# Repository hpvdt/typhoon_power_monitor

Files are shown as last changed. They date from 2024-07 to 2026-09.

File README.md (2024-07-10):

# Typhoon Power Monitor

General template repository for our hardware projects, especially one-off and self-contained projects like custom test equipment. This template assumes that the hardware is being designed in KiCad.

## Organization

Pretty self-explanitory, put hardware related files into the `hardware` folder, firmware in the `firmware` folder. Other folders can be added as needed: for example a `media` folder is handy for storing pictures related to a project which can be used in documentation.

## Conventions

Partly for consistency, partly for functionality; please follow the following conventions:

- Try to keep folder names to single words and all lowercase
- Use underscores to separate words in names (e.g. `board_rev1`). **DO NOT USE SPACES! ESPECIALLY FOR FOLDERS CONTAINING CODE!** Spaces in file paths may cause issues in compilers and such so best to avoid them entirely.

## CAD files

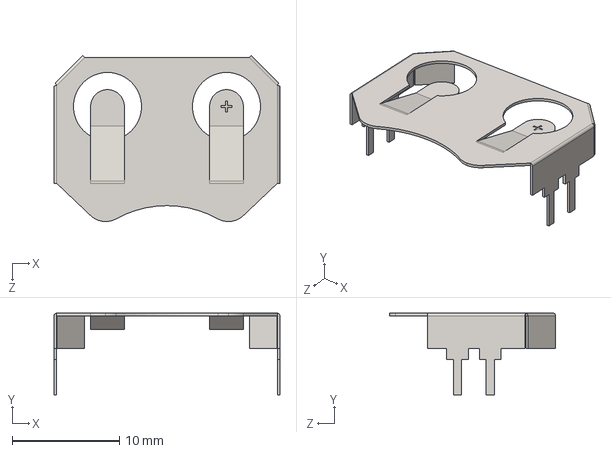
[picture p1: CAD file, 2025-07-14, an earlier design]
hardware/rev2/power_rev2/3dmodels/BAT-HLD-001-THM.stp
21.1 x 7.62 x 15.5 mm

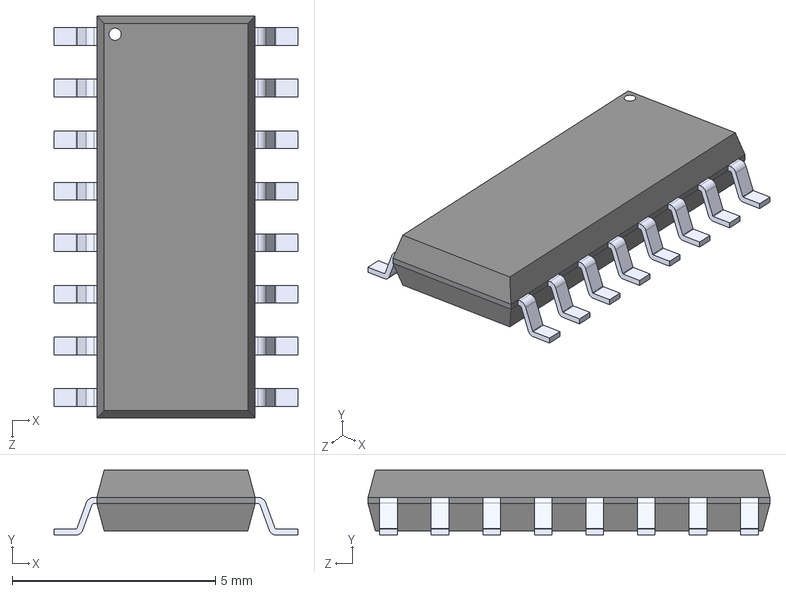
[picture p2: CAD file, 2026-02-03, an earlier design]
hardware/rev3/nexus_power_rev3/HX711/HX711.step
6.00 x 1.60 x 9.90 mm

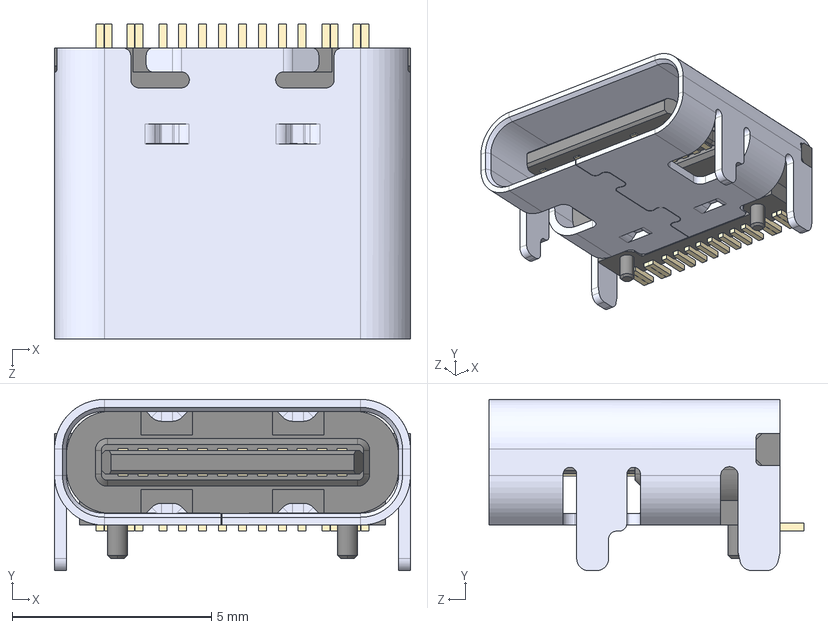
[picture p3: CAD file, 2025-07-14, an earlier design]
hardware/rev2/power_rev2/3dmodels/TYPE-C-31-M-12.step
8.94 x 4.30 x 7.90 mm

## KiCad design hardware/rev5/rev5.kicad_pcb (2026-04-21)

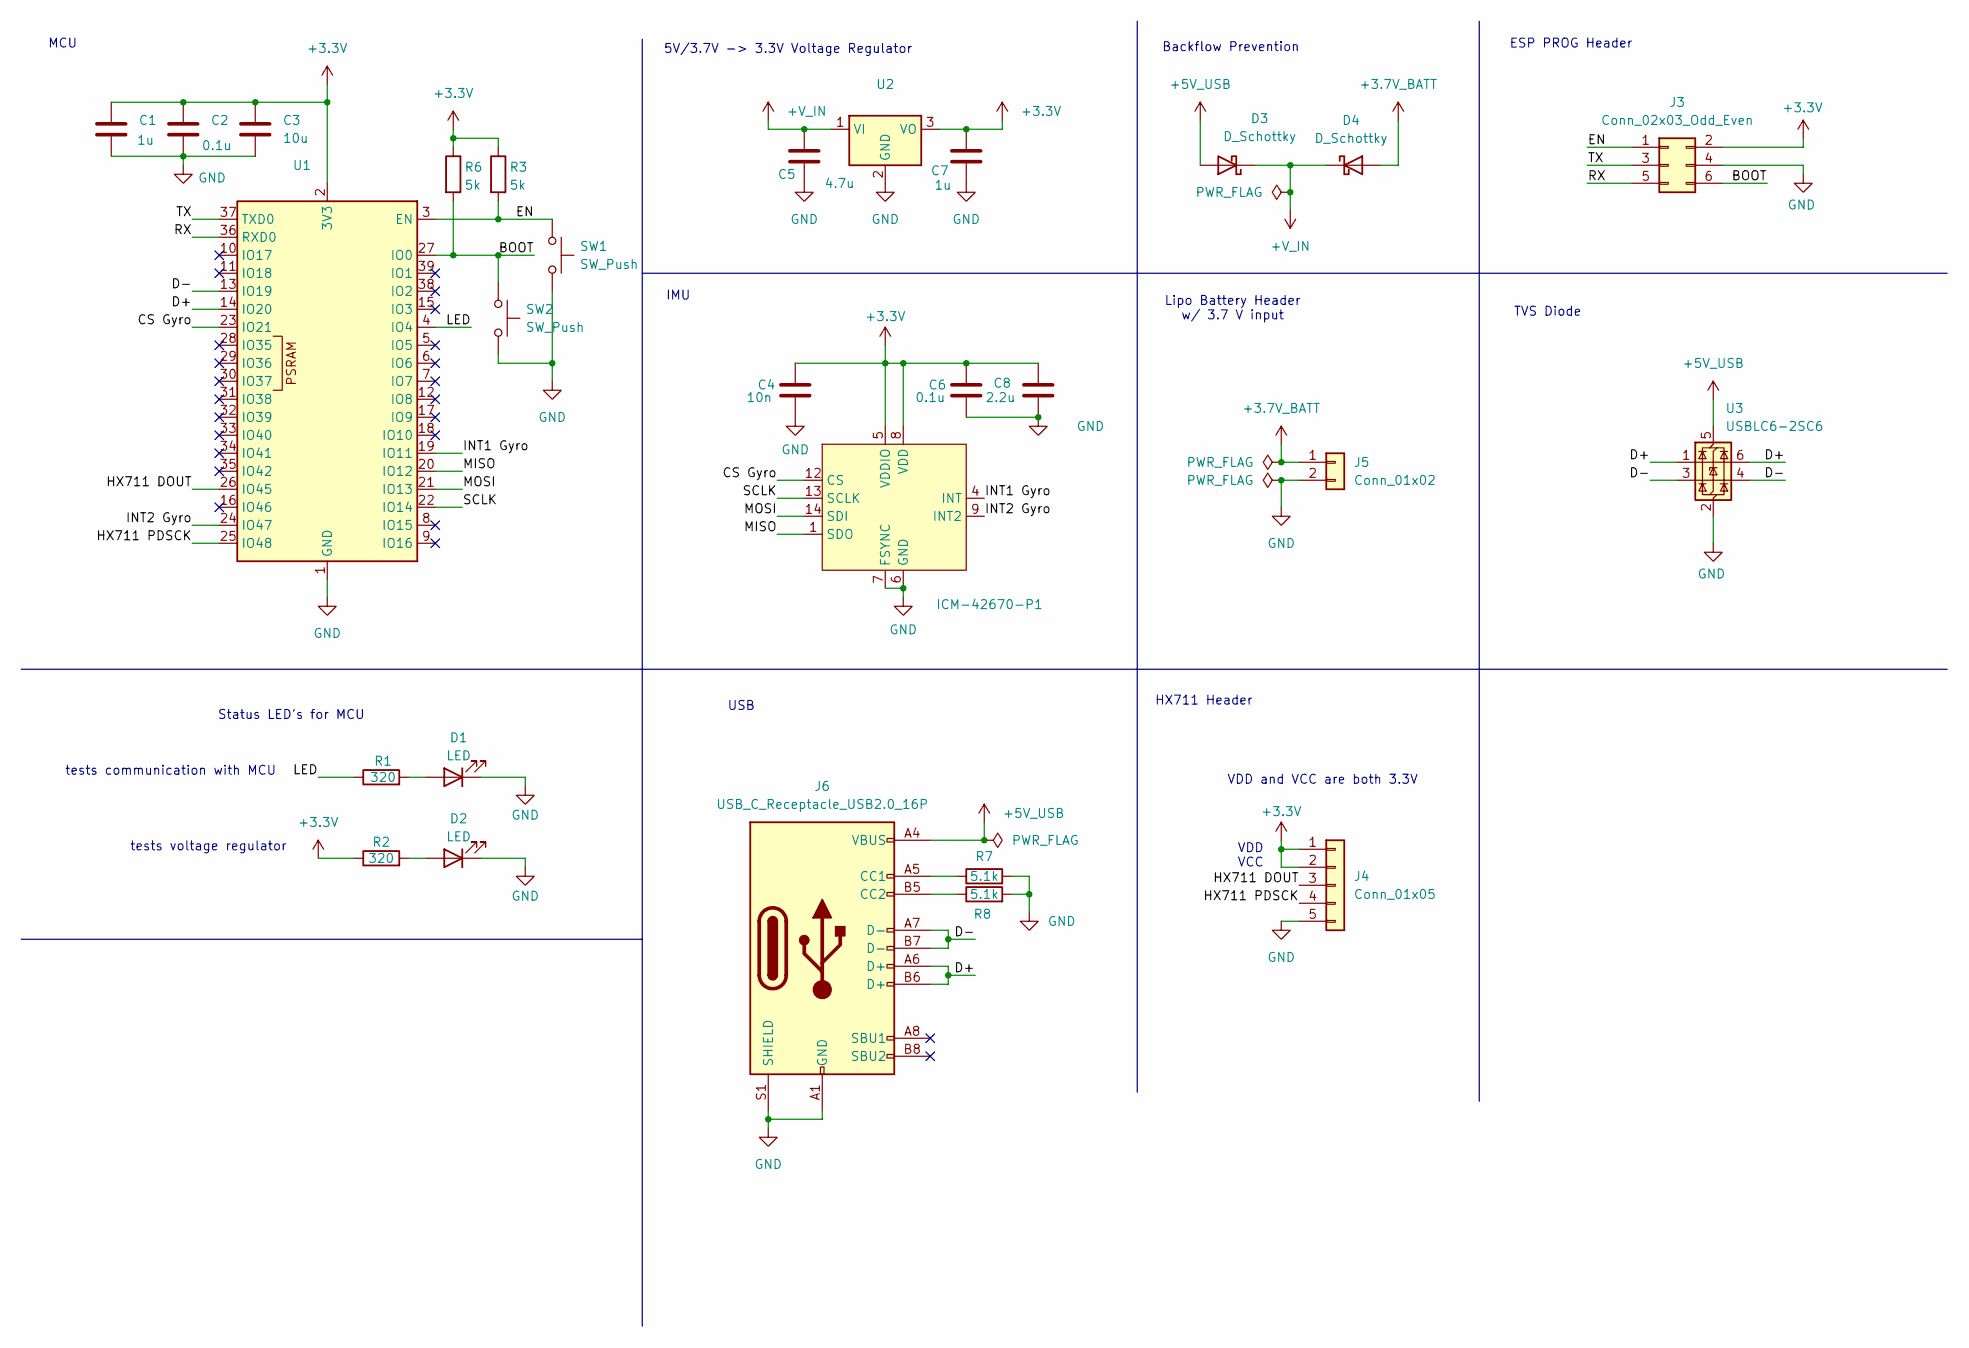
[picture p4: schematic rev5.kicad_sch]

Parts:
C1, C7: 1u; C_0805_2012Metric; Part number CL21B105KAFNNNE
C2, C6: 0.1u; C_0805_2012Metric; Part number C0805C104K5RACTU
C3: 10u; C_0805_2012Metric; Part number CL10A106KP8NNNC
C4: 10n; C_0805_2012Metric; Part number C0805C103K5RACTU
C5: 4.7u; C_0805_2012Metric; Part number CL21A475KAQNNNE
C8: 2.2u; C_0805_2012Metric; Part number CL21B225KAFNNNE
D1, D2: LED; LED_0805_2012Metric; Part number LTST-C170GKT
D3, D4: D_Schottky; D_SOD-123
ICM-42670-P1: LGA-14_3x2.5mm_P0.5mm_LayoutBorder3x4y; Part number ICM-42670-P
J3: Conn_02x03_Odd_Even; IDC-Header_2x03_P2.54mm_Vertical
J4: Conn_01x05; JST_XH_S5B-XH-A-1_1x05_P2.50mm_Horizontal
J5: Conn_01x02; JST_PH_S2B-PH-K_1x02_P2.00mm_Horizontal
J6: USB_C_Receptacle_USB2.0_16P; USB_C_Receptacle_JAE_DX07S016JA1R1500
R1, R2: 320; R_0805_2012Metric; Part number RT0805BRD07320RL
R3, R6: 5k; R_0805_2012Metric_Pad1.20x1.40mm_HandSolder
R7, R8: 5.1k; R_0805_2012Metric; Part number RMCF0805JT5K10
SW1, SW2: SW_Push; SW_SPST_SKQG_WithStem
U1: ESP32-S3-WROOM-1; Part number ESP32-S3-WROOM-1-N4R2
U2: SOT-223-3_TabPin2; Part number MCP1825ST-3302E/DB
U3: USBLC6-2SC6; SOT-23-6

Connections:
+3.3V: C1.1, C2.1, C3.1, C4.2, C6.2, C7.2, C8.2, ICM-42670-P1.5 (VDDIO), ICM-42670-P1.8 (VDD), J3.2, J4.1, J4.2, R2.1, R3.1, R6.1, U1.2 (3V3), U2.3 (VO); also elsewhere on the board
+3.7V_BATT: D4.2 (A), J5.1
+5V_USB: D3.2 (A), J6.A4 (VBUS), J6.A9 (VBUS), J6.B4 (VBUS), J6.B9 (VBUS), U3.5 (VBUS)
+V_IN: C5.2, D3.1 (K), D4.1 (K), U2.1 (VI)
/BOOT: J3.6, R6.2, SW2.1, U1.27 (IO0)
/CS Gyro: ICM-42670-P1.12 (CS), U1.23 (IO21); also elsewhere on the board
/D+: J6.A6 (D+), J6.B6 (D+), U1.14 (IO20), U3.1 (I/O1), U3.6 (I/O1)
/D-: J6.A7 (D-), J6.B7 (D-), U1.13 (IO19), U3.3 (I/O2), U3.4 (I/O2)
/EN: J3.1, R3.2, SW1.1, U1.3 (EN)
/HX711 DOUT: J4.3, U1.26 (IO45)
/HX711 PDSCK: J4.4, U1.25 (IO48)
/INT1 Gyro: ICM-42670-P1.4 (INT), U1.19 (IO11); also elsewhere on the board
/INT2 Gyro: ICM-42670-P1.9 (INT2), U1.24 (IO47); also elsewhere on the board
/LED: R1.1, U1.4 (IO4)
/MISO: ICM-42670-P1.1 (SDO), U1.20 (IO12); also elsewhere on the board
/MOSI: ICM-42670-P1.14 (SDI), U1.21 (IO13); also elsewhere on the board
/RX: J3.5, U1.36 (RXD0)
/SCLK: ICM-42670-P1.13 (SCLK), U1.22 (IO14); also elsewhere on the board
/TX: J3.3, U1.37 (TXD0)
GND: C1.2, C2.2, C3.2, C4.1, C5.1, C6.1, C7.1, C8.1, D1.1 (K), D2.1 (K), ICM-42670-P1.6 (GND), ICM-42670-P1.7 (FSYNC), J3.4, J4.5, J5.2, J6.A1 (GND), J6.A12 (GND), J6.B1 (GND), J6.B12 (GND), J6.S1 (SHIELD), R7.2, R8.2, SW1.2, SW2.2, U1.1 (GND), U1.40 (GND), U1.41 (GND), U2.2 (GND), U3.2 (GND); also elsewhere on the board
unnamed: D1.2 (A), R1.2
unnamed: D2.2 (A), R2.2
unnamed: J6.A5 (CC1), R7.1
unnamed: J6.B5 (CC2), R8.1

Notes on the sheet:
ESP PROG Header
Lipo Battery Header w/ 3.7 V input
Status LED's for MCU
MCU
TVS Diode
tests communication with MCU
IMU
VDD and VCC are both 3.3V
5V/3.7V -> 3.3V Voltage Regulator
tests voltage regulator
Backflow Prevention
HX711 Header
USB
VCC
VDD

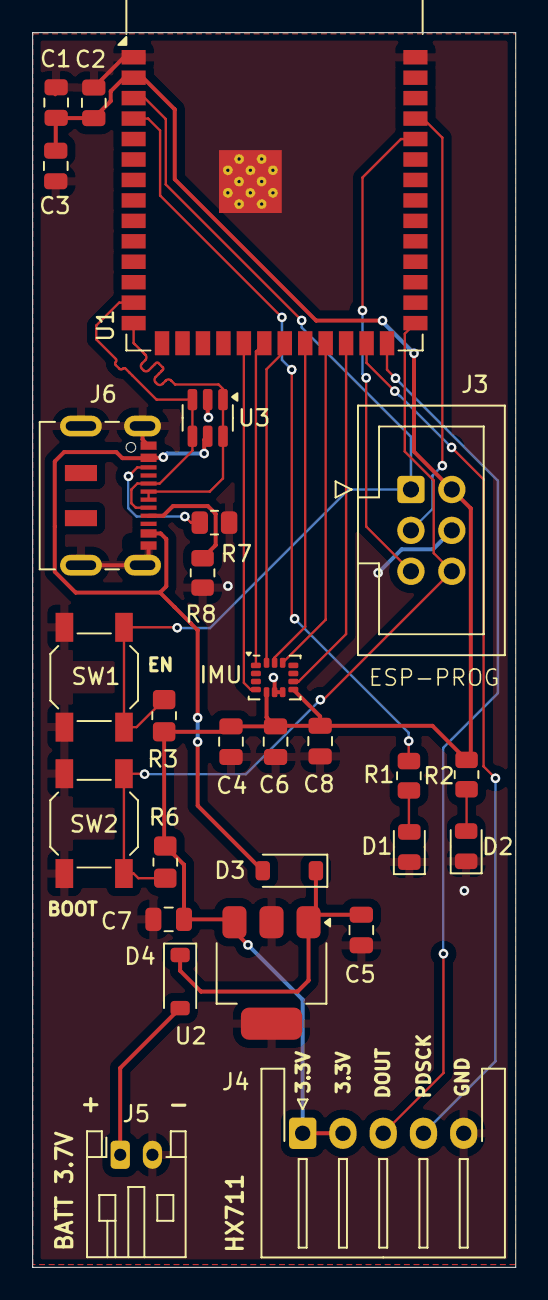
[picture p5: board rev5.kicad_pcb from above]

Board: 2 copper layers, 30.0 x 76.7 mm, 28 parts (0 on the bottom side), 24 nets.

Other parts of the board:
IMU: LGA-14_3x2.5mm_P0.5mm_LayoutBorder3x4y

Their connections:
+3.3V: IMU.5 (VDDIO), IMU.8 (VDD); also elsewhere on the board
/CS Gyro: IMU.12 (CS); also elsewhere on the board
/INT1 Gyro: IMU.4 (INT); also elsewhere on the board
/INT2 Gyro: IMU.9 (INT2); also elsewhere on the board
/MISO: IMU.1 (SDO); also elsewhere on the board
/MOSI: IMU.14 (SDI); also elsewhere on the board
/SCLK: IMU.13 (SCLK); also elsewhere on the board
GND: IMU.6 (GND), IMU.7 (FSYNC); also elsewhere on the board

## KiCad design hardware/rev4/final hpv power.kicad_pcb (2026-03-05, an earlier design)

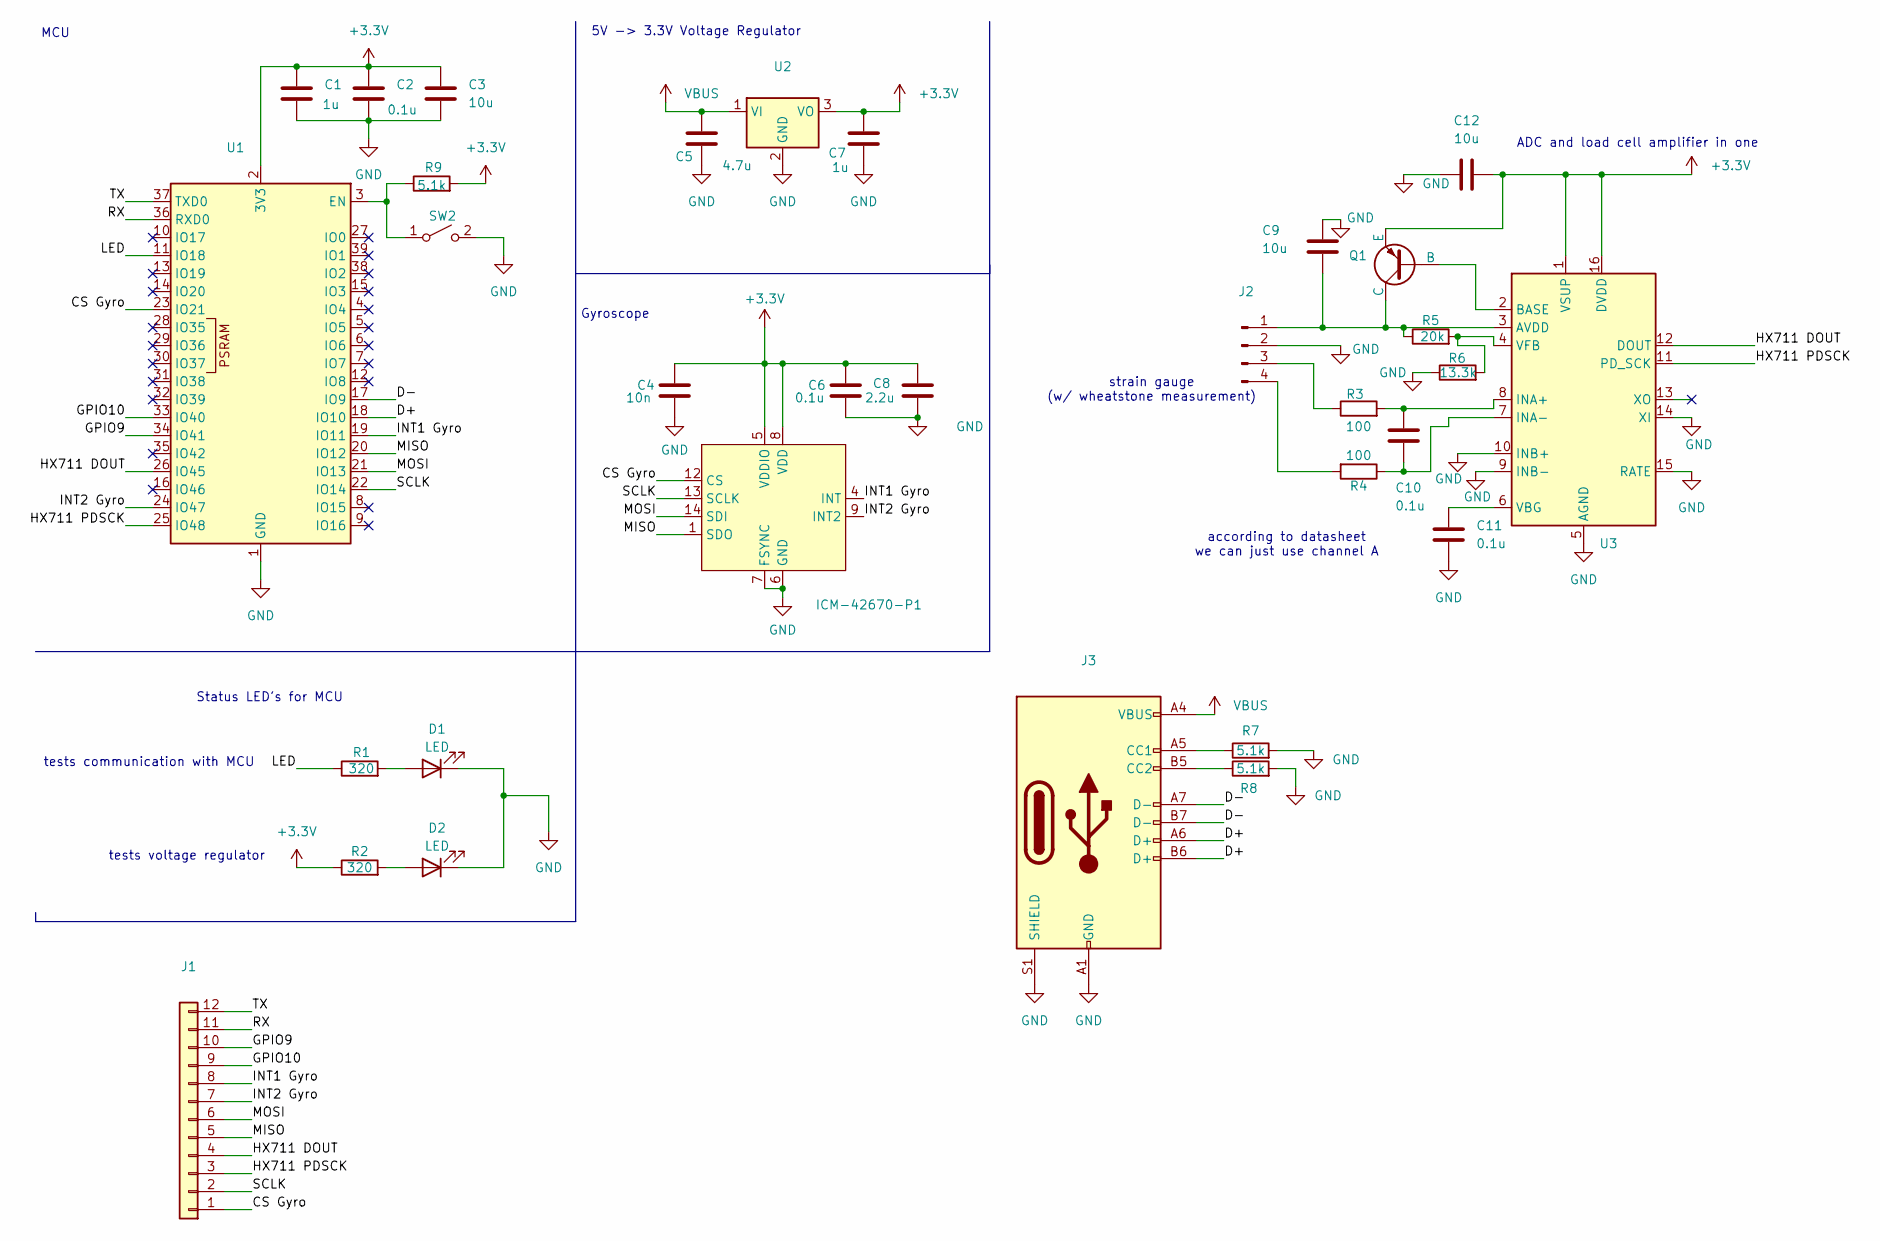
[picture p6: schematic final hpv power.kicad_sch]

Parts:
C1, C7: 1u; C_0805_2012Metric; Part number CL21B105KAFNNNE
C2, C6, C10, C11: 0.1u; C_0805_2012Metric; Part number C0805C104K5RACTU
C3, C9, C12: 10u; C_0805_2012Metric; Part number CL10A106KP8NNNC
C4: 10n; C_0805_2012Metric; Part number C0805C103K5RACTU
C5: 4.7u; C_0805_2012Metric; Part number CL21A475KAQNNNE
C8: 2.2u; C_0805_2012Metric; Part number CL21B225KAFNNNE
D1, D2: LED; LED_0805_2012Metric; Part number LTST-C170GKT
ICM-42670-P1: LGA-14_3x2.5mm_P0.5mm_LayoutBorder3x4y; Part number ICM-42670-P
J1: JST_EH_B12B-EH-A_1x12_P2.50mm_Vertical; Part number B12B-XH-A
J2: JST_EH_B4B-EH-A_1x04_P2.50mm_Vertical; Part number B4B-XH-A
J3: USB_C_Receptacle_GCT_USB4110; Part number USB4110-GF-A
Q1: SOT-23; Part number MMSS8550-L-TP
R1, R2: 320; R_0805_2012Metric; Part number RT0805BRD07320RL
R3, R4: 100; R_0805_2012Metric; Part number CRCW0805100RFKEA
R5: 20k; R_0805_2012Metric; Part number ERA-6AEB203V
R6: 13.3k; R_0805_2012Metric; Part number CRCW080513K3FKEA
R7, R8, R9: 5.1k; R_0805_2012Metric; Part number RMCF0805JT5K10
SW2: SW_PUSH_6mm_H4.3mm; Part number 1301.9314.24
U1: ESP32-S3-WROOM-1; Part number ESP32-S3-WROOM-1-N4R2
U2: SOT-223-3_TabPin2; Part number MCP1825ST-3302E/DB
U3: SOP127P600X180-16N; Part number 13879

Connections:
+3.3V: C1.1, C2.1, C3.1, C4.2, C6.2, C7.2, C8.2, C12.1, ICM-42670-P1.5 (VDDIO), ICM-42670-P1.8 (VDD), Q1.3 (E), R2.1, R9.2, U1.2 (3V3), U2.3 (VO), U3.1 (VSUP), U3.16 (DVDD)
/CS Gyro: ICM-42670-P1.12 (CS), J1.1, U1.23 (IO21)
/D+: J3.A6 (D+), J3.B6 (D+), U1.18 (IO10)
/D-: J3.A7 (D-), J3.B7 (D-), U1.17 (IO9)
/GPIO9: J1.10, U1.34 (IO41)
/GPIO10: J1.9, U1.33 (IO40)
/HX711 DOUT: J1.4, U1.26 (IO45), U3.12 (DOUT)
/HX711 PDSCK: J1.3, U1.25 (IO48), U3.11 (PD_SCK)
/INT1 Gyro: ICM-42670-P1.4 (INT), J1.8, U1.19 (IO11)
/INT2 Gyro: ICM-42670-P1.9 (INT2), J1.7, U1.24 (IO47)
/LED: R1.1, U1.11 (IO18)
/MISO: ICM-42670-P1.1 (SDO), J1.5, U1.20 (IO12)
/MOSI: ICM-42670-P1.14 (SDI), J1.6, U1.21 (IO13)
/RX: J1.11, U1.36 (RXD0)
/SCLK: ICM-42670-P1.13 (SCLK), J1.2, U1.22 (IO14)
/TX: J1.12, U1.37 (TXD0)
GND: C1.2, C2.2, C3.2, C4.1, C5.1, C6.1, C7.1, C8.1, C9.1, C11.2, C12.2, D1.1 (K), D2.1 (K), ICM-42670-P1.6 (GND), ICM-42670-P1.7 (FSYNC), J2.2, J3.A1 (GND), J3.A12 (GND), J3.B1 (GND), J3.B12 (GND), J3.S1 (SHIELD), R6.1, R7.2, R8.2, SW2.2 (B), U1.1 (GND), U1.40 (GND), U1.41 (GND), U2.2 (GND), U3.5 (AGND), U3.9 (INB-), U3.10 (INB+), U3.14 (XI), U3.15 (RATE)
unnamed: D1.2 (A), R1.2
unnamed: D2.2 (A), R2.2
unnamed: C9.2, J2.1, Q1.1 (C), R5.1, U3.3 (AVDD)
unnamed: J2.3, R3.1
unnamed: J2.4, R4.2
unnamed: J3.A5 (CC1), R7.1
unnamed: J3.B5 (CC2), R8.1
unnamed: Q1.2 (B), U3.2 (BASE)
unnamed: R9.1, SW2.1 (A), U1.3 (EN)
unnamed: C10.1, R3.2, U3.8 (INA+)
unnamed: C10.2, R4.1, U3.7 (INA-)
unnamed: C11.1, U3.6 (VBG)
unnamed: R5.2, R6.2, U3.4 (VFB)
VBUS: C5.2, J3.A4 (VBUS), J3.A9 (VBUS), J3.B4 (VBUS), J3.B9 (VBUS), U2.1 (VI)

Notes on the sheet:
strain gauge (w/ wheatstone measurement)
ADC and load cell amplifier in one
according to datasheet we can just use channel A
Status LED's for MCU
MCU
tests communication with MCU
Gyroscope
5V -> 3.3V Voltage Regulator
tests voltage regulator

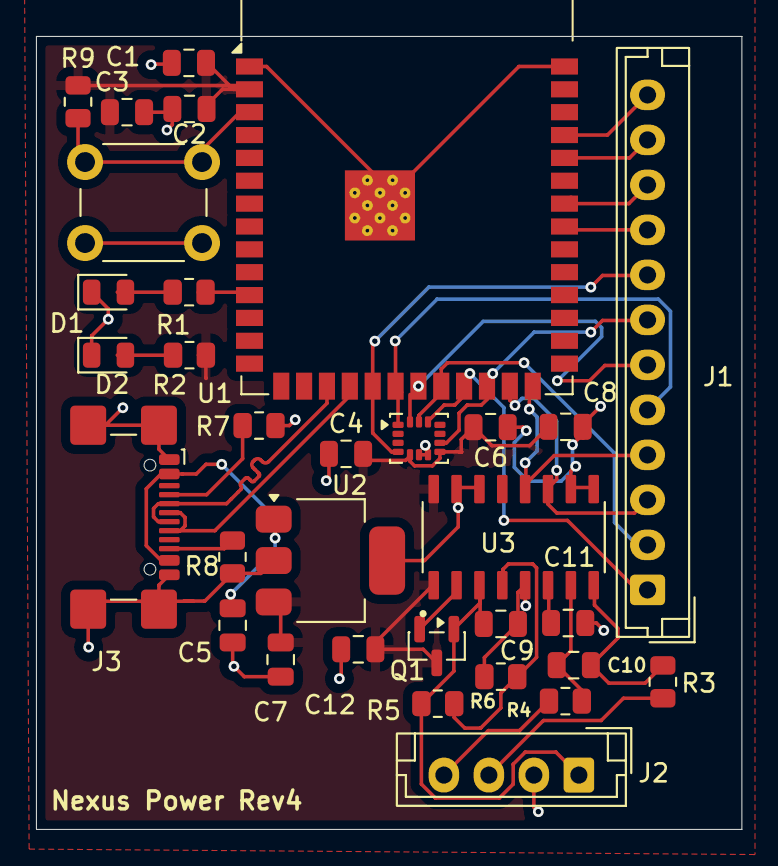
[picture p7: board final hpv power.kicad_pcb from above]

Board: 2 copper layers, 39.2 x 44.1 mm, 32 parts (0 on the bottom side), 31 nets.

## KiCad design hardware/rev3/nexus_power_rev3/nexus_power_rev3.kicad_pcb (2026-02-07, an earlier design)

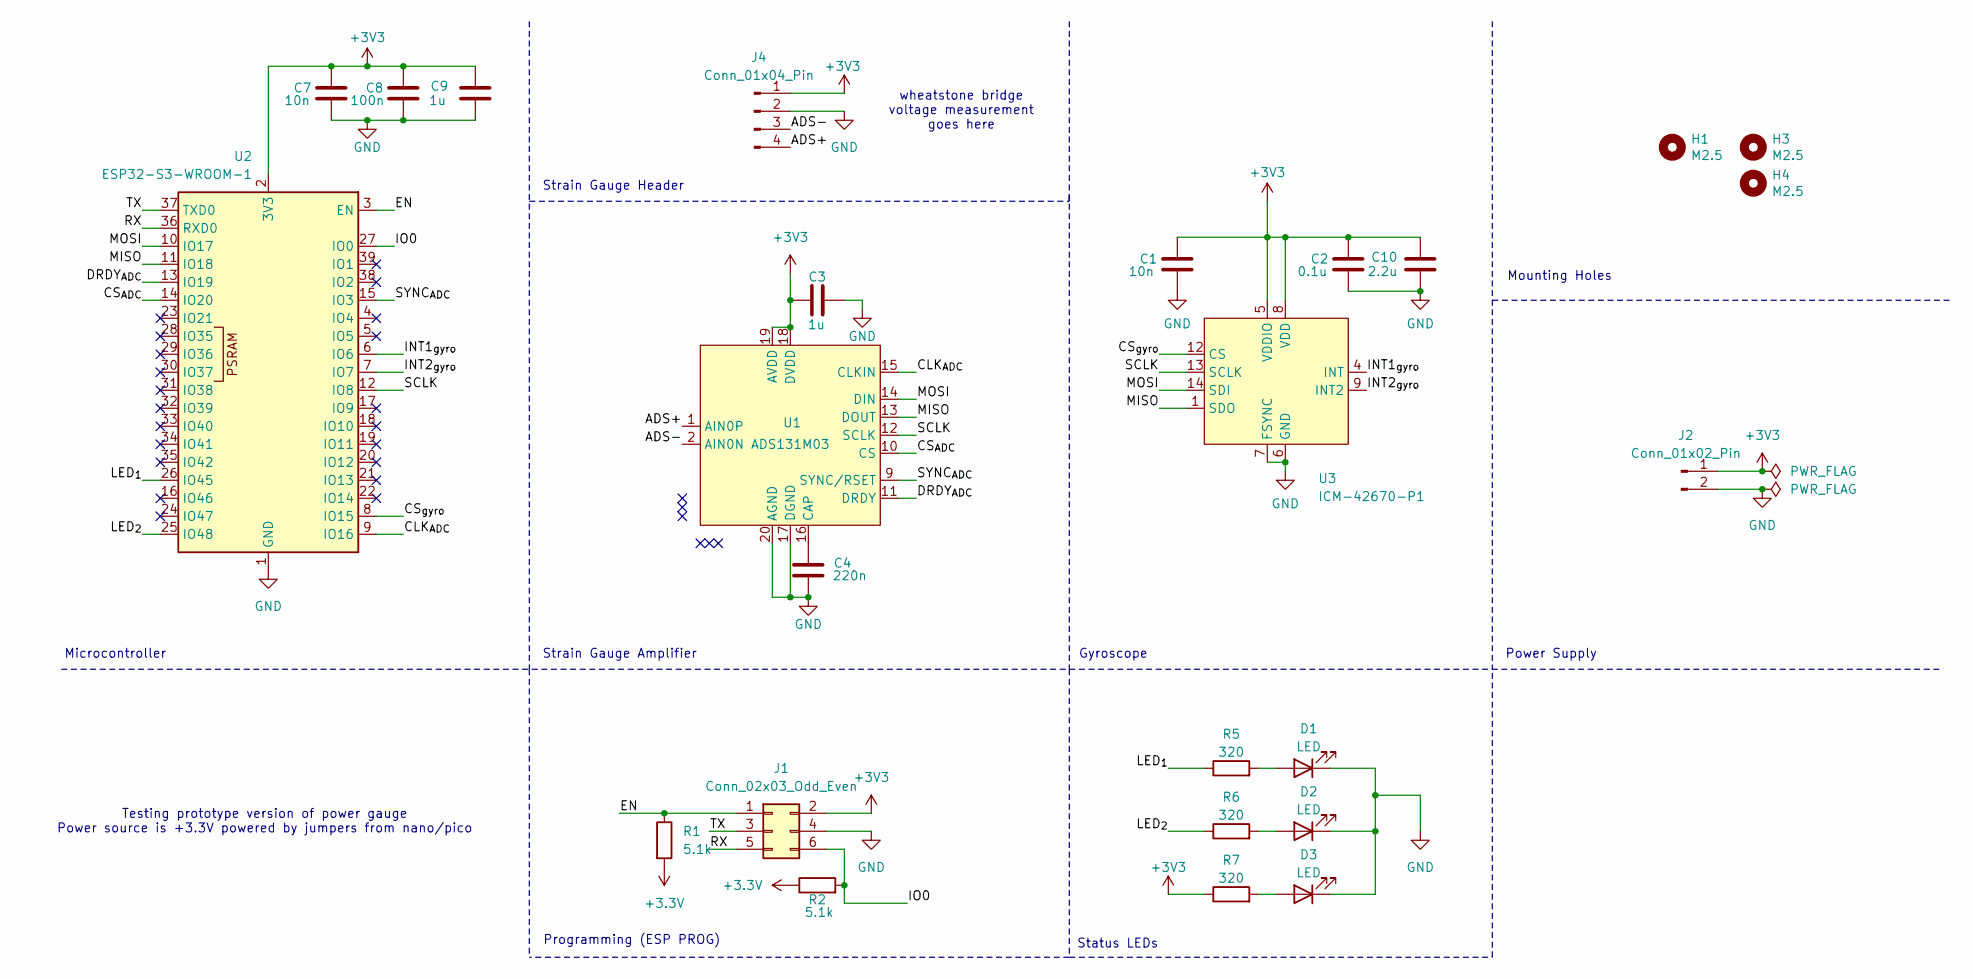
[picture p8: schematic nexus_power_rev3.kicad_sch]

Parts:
C1, C7: 10n; C_0603_1608Metric
C2: 0.1u; C_0603_1608Metric
C3, C9: 1u; C_0603_1608Metric
C4: 220n; C_0603_1608Metric
C8: 100n; C_0603_1608Metric
C10: 2.2u; C_0603_1608Metric
D1, D2, D3: LED; LED_0603_1608Metric
H1, H3, H4: M2.5; MountingHole_2.7mm_M2.5
J1: Conn_02x03_Odd_Even; IDC-Header_2x03_P2.54mm_Vertical
J2: Conn_01x02_Pin; PinHeader_1x02_P2.00mm_Vertical
J4: Conn_01x04_Pin; JST_XH_S4B-XH-A_1x04_P2.50mm_Horizontal
R1, R2: 5.1k; R_0603_1608Metric
R5, R6, R7: 320; R_0603_1608Metric
U1: ADS131M03; WQFN-20-1EP_3x3mm_P0.4mm_EP1.7x1.7mm
U2: ESP32-S3-WROOM-1
U3: ICM-42670-P1; LGA-14_3x2.5mm_P0.5mm_LayoutBorder3x4y

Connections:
+3.3V: R1.2, R2.1
+3V3: C1.2, C2.2, C3.2, C7.2, C8.2, C9.2, C10.2, J1.2, J2.1, J4.1, R7.1, U1.18 (DVDD), U1.19 (AVDD), U2.2 (3V3), U3.5 (VDDIO), U3.8 (VDD)
/ADS+: J4.4, U1.1 (AIN0P)
/ADS-: J4.3, U1.2 (AIN0N)
/CLK_{ADC}: U1.15 (CLKIN), U2.9 (IO16)
/CS_{ADC}: U1.10 (CS), U2.14 (IO20)
/CS_{gyro}: U2.8 (IO15), U3.12 (CS)
/DRDY_{ADC}: U1.11 (DRDY), U2.13 (IO19)
/EN: J1.1, R1.1, U2.3 (EN)
/INT1_{gyro}: U2.6 (IO6), U3.4 (INT)
/INT2_{gyro}: U2.7 (IO7), U3.9 (INT2)
/IO0: J1.6, R2.2, U2.27 (IO0)
/LED_{1}: R5.1, U2.26 (IO45)
/LED_{2}: R6.1, U2.25 (IO48)
/MISO: U1.13 (DOUT), U2.11 (IO18), U3.1 (SDO)
/MOSI: U1.14 (DIN), U2.10 (IO17), U3.14 (SDI)
/RX: J1.5, U2.36 (RXD0)
/SCLK: U1.12 (SCLK), U2.12 (IO8), U3.13 (SCLK)
/SYNC_{ADC}: U1.9 (SYNC/RSET), U2.15 (IO3)
/TX: J1.3, U2.37 (TXD0)
GND: C1.1, C2.1, C3.1, C4.1, C7.1, C8.1, C9.1, C10.1, D1.1 (K), D2.1 (K), D3.1 (K), J1.4, J2.2, J4.2, U1.17 (DGND), U1.20 (AGND), U2.1 (GND), U2.40 (GND), U2.41 (GND), U3.6 (GND), U3.7 (FSYNC)
unnamed: D1.2 (A), R5.2
unnamed: D2.2 (A), R6.2
unnamed: D3.2 (A), R7.2
unnamed: C4.2, U1.16 (CAP)

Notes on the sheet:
Programming (ESP PROG)
Strain Gauge Amplifier
Strain Gauge Header
Gyroscope
Microcontroller
Status LEDs
Testing prototype version of power gauge Power source is +3.3V powered by jumpers from nano/pico
wheatstone bridge voltage measurement goes here
Mounting Holes
Power Supply

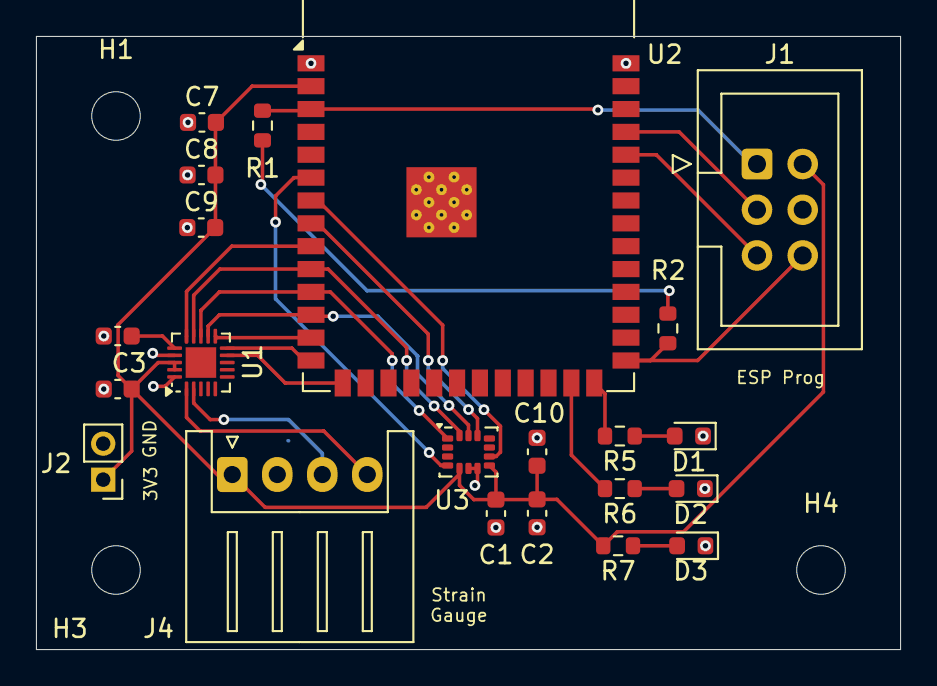
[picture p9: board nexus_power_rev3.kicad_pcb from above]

Board: 2 copper layers, 48.0 x 34.1 mm, 25 parts (0 on the bottom side), 25 nets.

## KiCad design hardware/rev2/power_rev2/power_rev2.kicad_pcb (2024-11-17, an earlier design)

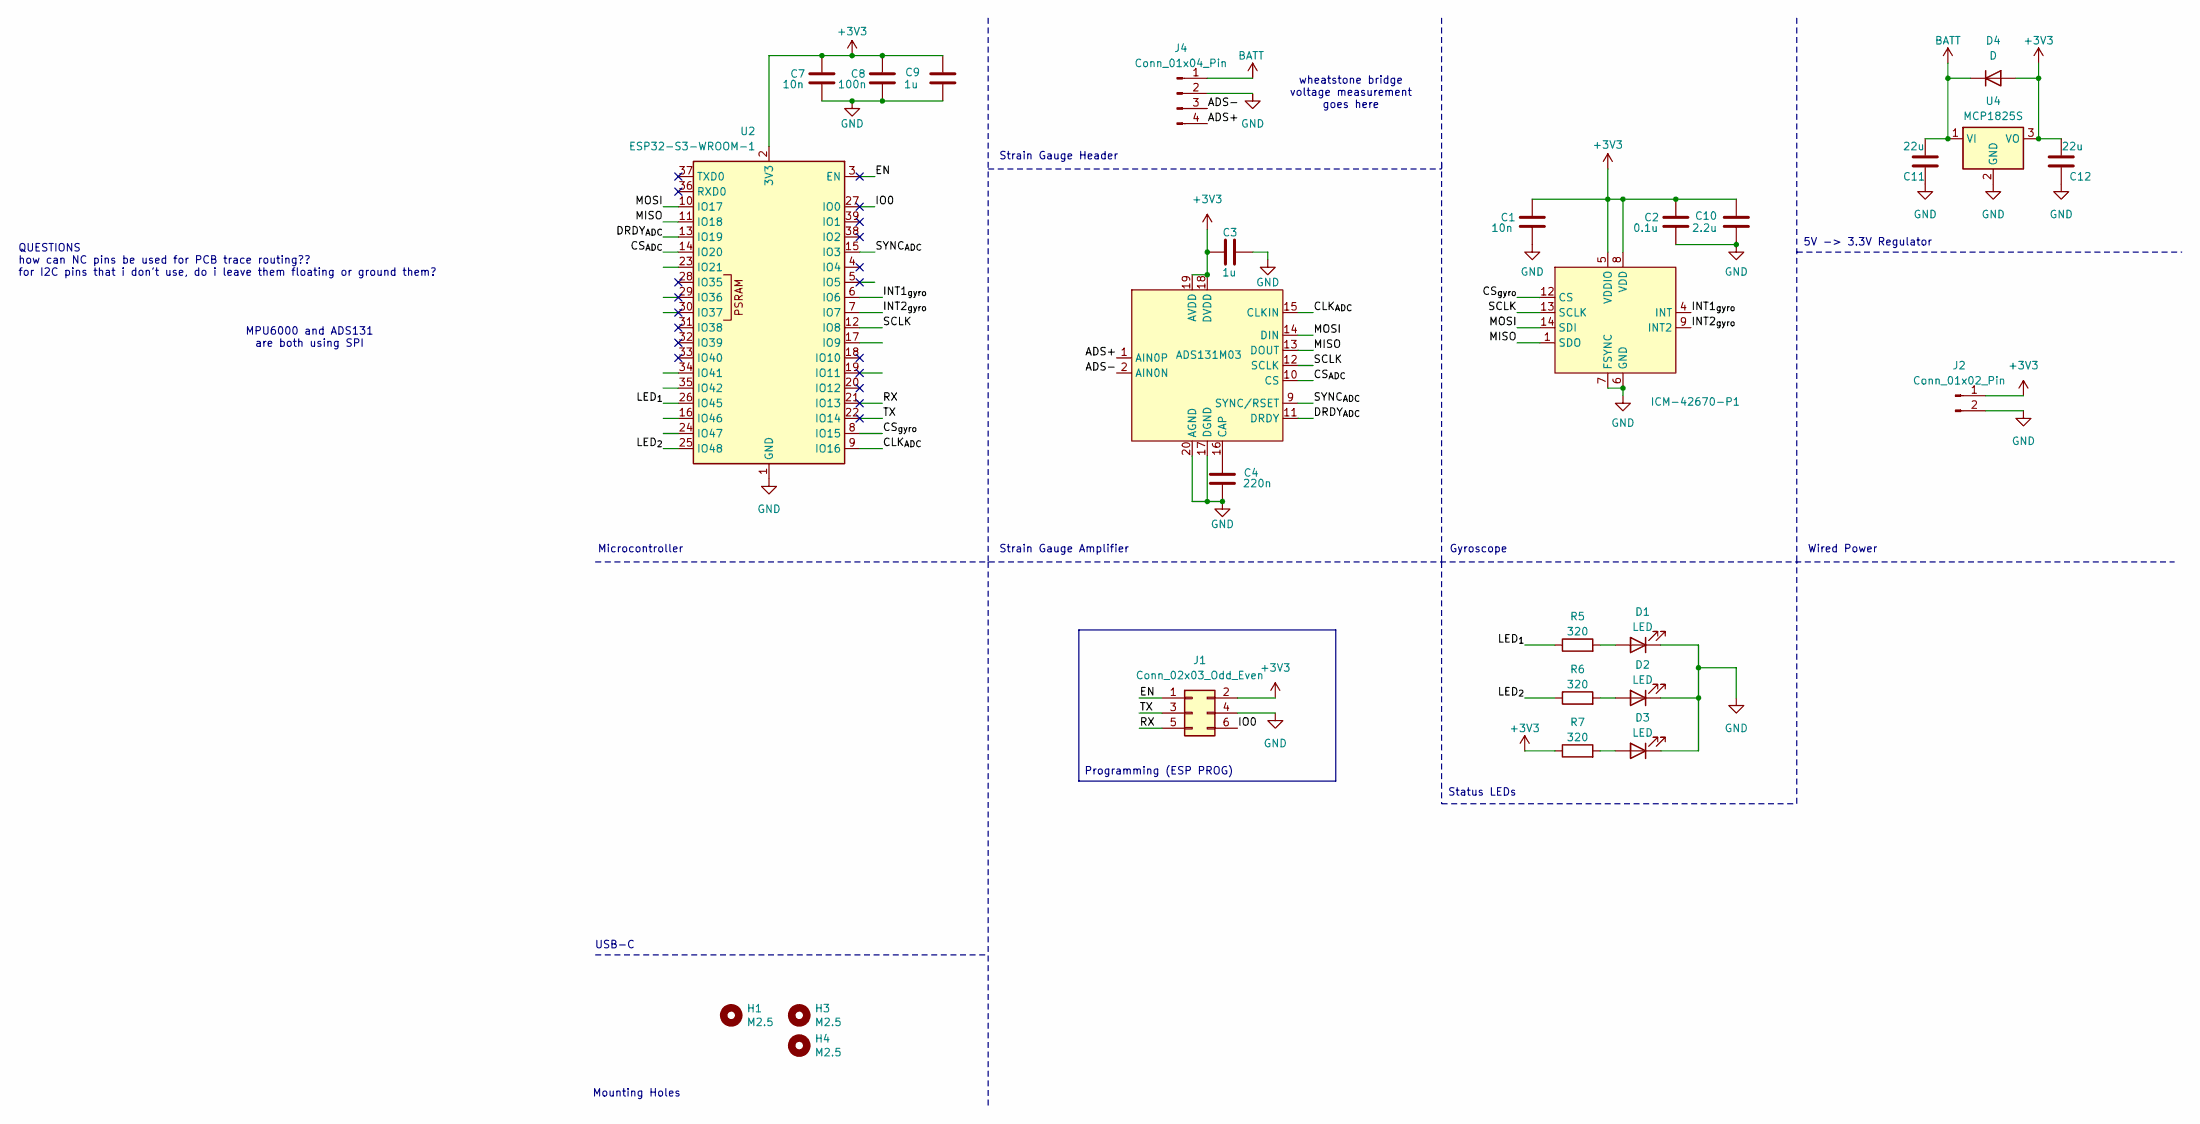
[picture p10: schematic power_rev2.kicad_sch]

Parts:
ADS131M03: ads
C1, C7: 10n; C_0402_1005Metric
C2: 0.1u; C_0402_1005Metric
C3, C9: 1u; C_0402_1005Metric
C4: 220n; C_0402_1005Metric
C8: 100n; C_0402_1005Metric
C10: 2.2u; C_0402_1005Metric
C11, C12: 22u; C_0402_1005Metric
D1, D2, D3: LED; LED_0402_1005Metric
D4: D; SD103CW
H1, H3, H4: M2.5; MountingHole_2.7mm_M2.5
ICM-42670-P1: LGA-14_3x2.5mm_P0.5mm_LayoutBorder3x4y
J1: Conn_02x03_Odd_Even; IDC-Header_2x03_P2.54mm_Vertical
J2: Conn_01x02_Pin; PinHeader_1x02_P1.27mm_Vertical
J4: Conn_01x04_Pin; JST_EH_S4B-EH_1x04_P2.50mm_Horizontal
R5, R6, R7: 320; R_0402_1005Metric
U2: ESP32-S3-WROOM-1
U4: MCP1825S; SOT-223-3_TabPin2

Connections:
+3V3: ADS131M03.18 (DVDD), ADS131M03.19 (AVDD), C1.2, C2.2, C3.2, C7.2, C8.2, C9.2, C10.2, C12.2, D4.2 (A), ICM-42670-P1.5 (VDDIO), ICM-42670-P1.8 (VDD), J1.2, J2.1, R7.1, U2.2 (3V3), U4.3 (VO)
/ADS+: ADS131M03.1 (AIN0P), J4.4
/ADS-: ADS131M03.2 (AIN0N), J4.3
/CLK_{ADC}: ADS131M03.15 (CLKIN), U2.9 (IO16)
/CS_{ADC}: ADS131M03.10 (CS), U2.14 (IO20)
/CS_{gyro}: ICM-42670-P1.12 (CS), U2.8 (IO15)
/DRDY_{ADC}: ADS131M03.11 (DRDY), U2.13 (IO19)
/EN: J1.1, U2.3 (EN)
/INT1_{gyro}: ICM-42670-P1.4 (INT), U2.6 (IO6)
/INT2_{gyro}: ICM-42670-P1.9 (INT2), U2.7 (IO7)
/IO0: J1.6, U2.27 (IO0)
/LED_{1}: R5.1, U2.26 (IO45)
/LED_{2}: R6.1, U2.25 (IO48)
/MISO: ADS131M03.13 (DOUT), ICM-42670-P1.1 (SDO), U2.11 (IO18)
/MOSI: ADS131M03.14 (DIN), ICM-42670-P1.14 (SDI), U2.10 (IO17)
/RX: J1.5, U2.21 (IO13)
/SCLK: ADS131M03.12 (SCLK), ICM-42670-P1.13 (SCLK), U2.12 (IO8)
/SYNC_{ADC}: ADS131M03.9 (SYNC/RSET), U2.15 (IO3)
/TX: J1.3, U2.22 (IO14)
BATT: C11.2, D4.1 (K), J4.1, U4.1 (VI)
GND: ADS131M03.17 (DGND), ADS131M03.20 (AGND), ADS131M03.21, C1.1, C2.1, C3.1, C4.1, C7.1, C8.1, C9.1, C10.1, C11.1, C12.1, D1.1 (K), D2.1 (K), D3.1 (K), ICM-42670-P1.6 (GND), ICM-42670-P1.7 (FSYNC), J1.4, J2.2, J4.2, U2.1 (GND), U2.40 (GND), U2.41 (GND), U4.2 (GND)
unnamed: ADS131M03.16 (CAP), C4.2
unnamed: D1.2 (A), R5.2
unnamed: D2.2 (A), R6.2
unnamed: D3.2 (A), R7.2

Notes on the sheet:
Strain Gauge Header
Strain Gauge Amplifier
wheatstone bridge voltage measurement goes here
Status LEDs
Mounting Holes
Programming (ESP PROG)
Microcontroller
5V -> 3.3V Regulator
MPU6000 and ADS131 are both using SPI
Wired Power
QUESTIONS how can NC pins be used for PCB trace routing?? for I2C pins that i don't use, do i leave them floating or ground them?
Gyroscope
USB-C

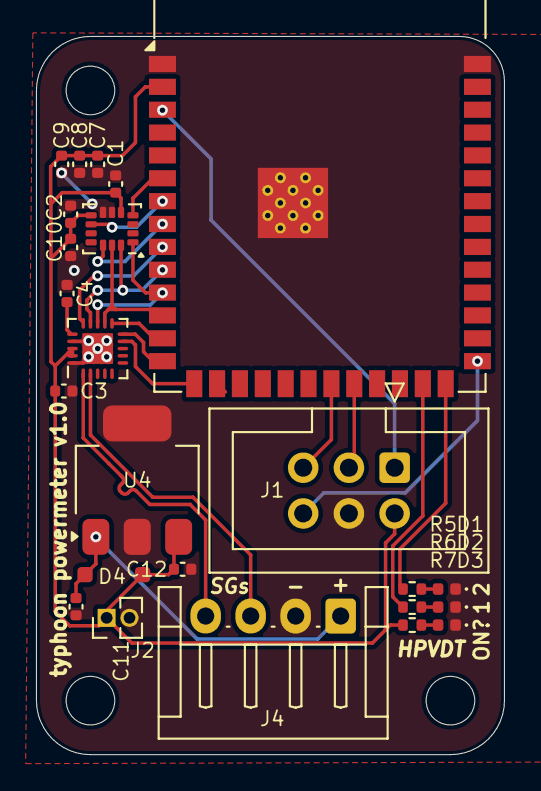
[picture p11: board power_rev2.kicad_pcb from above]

Board: 2 copper layers, 26.0 x 39.9 mm, 27 parts (0 on the bottom side), 25 nets.

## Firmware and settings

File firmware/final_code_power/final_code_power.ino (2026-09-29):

#include "ICM42670P.h"
#include <SPI.h>
#include <WiFi.h>
#include <WebServer.h>

// ======================================================
//                    WIFI SETTINGS
// ======================================================

const char* ssid = "ESP32-Data-Server";
const char* password = "12345678";

WebServer server(80);

// ======================================================
//                    BIKE CONSTANTS
// ======================================================

// in meters
const float crankLength = 0.06;
const float e = 2.7182818;

// ======================================================
//                    IMU PINS
// ======================================================

#define CS_pin 21
#define CLK_pin 14
#define MISO_pin 12
#define MOSI_pin 13

SPIClass* fspi = NULL;
ICM42670* IMU = NULL;

// ======================================================
//                    HX711 PINS
// ======================================================

const int hxClockPin = 48;
const int hxDataPin = 45;

// ======================================================
//                    GLOBAL VALUES
// ======================================================

float latestGyroX = 0;
float latestGyroY = 0;
float latestGyroZ = 0;

float latestAngularVelocity = 0;

float latestRawForce = 0;
float latestSlidingRaw = 0;    // 3-second sliding average raw force
float latestSlidingPower = 0;  // 3-second sliding average power

// Number of HX711 samples used for initial calibration
const int samples = 50;

float slope = 0;
float intercept = 0;

int initialForce = 0;

// ======================================================
//                3 SECOND TIMERS & WINDOWS
// ======================================================

const unsigned long measurementInterval = 1000;

// Time when the current measurement started
unsigned long measurementStartTime = 0;

// Sum of all HX711 readings during the period
long double hx711Sum = 0;

// Number of HX711 readings collected
unsigned long hx711Count = 0;

// IMU accumulation variables for 1-second averaging
float gyroSumX = 0;
float gyroSumY = 0;
float gyroSumZ = 0;
float angVelSum = 0;
unsigned long imuSampleCount = 0;

// 3-Second Sliding Window Buffers
const int windowSize = 3;
float powerWindow[windowSize] = { 0, 0, 0 };
int windowIndex = 0;

float rawWindow[windowSize] = { 0, 0, 0 };
int rawWindowIndex = 0;

// ======================================================
//                    HX711 FUNCTION
// ======================================================

long readHX711() {

  long count = 0;

  // Wait until HX711 is ready
  while (digitalRead(hxDataPin) == HIGH)
    ;

  // Read 24 bits
  for (int i = 0; i < 24; i++) {

    digitalWrite(hxClockPin, HIGH);

    count = count << 1;

    if (digitalRead(hxDataPin)) {
      count++;
    }

    digitalWrite(hxClockPin, LOW);
  }

  // 25th pulse → gain = 128
  digitalWrite(hxClockPin, HIGH);
  digitalWrite(hxClockPin, LOW);

  // Convert 24-bit signed value
  if (count & 0x800000) {
    count |= ~0xFFFFFF;
  }

  return count;
}

// ======================================================
//                    WEBSITE
// ======================================================

void handleRoot() {

  String html = R"rawliteral(
    <!DOCTYPE html>
    <html>

    <head>
      <title>ESP32 Power Meter</title>

      <style>

        body {
          font-family: Arial;
          text-align: center;
          margin-top: 40px;
        }

        .box {
          font-size: 28px;
          margin: 15px;
        }

      </style>

      <script>

        function updateData() {

          fetch('/data')
            .then(response => response.json())
            .then(data => {

              document.getElementById('gyroX').textContent = data.gyroX;
              document.getElementById('gyroY').textContent = data.gyroY;
              document.getElementById('gyroZ').textContent = data.gyroZ;
              document.getElementById('angularVelocity').textContent = data.angularVelocity;
              document.getElementById('rawValue').textContent = data.raw;
              document.getElementById('slidingRaw').textContent = data.slidingRaw;
              document.getElementById('slidingPower').textContent = data.slidingPower;

            });

        }

        setInterval(updateData, 1000);

        // Get the first reading immediately
        updateData();

      </script>

    </head>

    <body>

      <h1>ESP32 Cycling Power Meter</h1>

      <div class="box">
        <b>Gyro X:</b>
        <span id="gyroX">0</span> rad/s
      </div>

      <div class="box">
        <b>Gyro Y:</b>
        <span id="gyroY">0</span> rad/s
      </div>

      <div class="box">
        <b>Gyro Z:</b>
        <span id="gyroZ">0</span> rad/s
      </div>

      <div class="box">
        <b>Angular Velocity:</b>
        <span id="angularVelocity">0</span> rad/s
      </div>

      <div class="box">
        <b>Average Raw HX711:</b>
        <span id="rawValue">0</span>
      </div>

      <div class="box">
        <b>3-Sec Sliding Raw HX711:</b>
        <span id="slidingRaw">0</span>
      </div>

      <div class="box">
        <b>3-Sec Average Power:</b> 
        <span id="slidingPower">0</span> W
      </div>

    </body>
    </html>
  )rawliteral";

  server.send(200, "text/html", html);
}

// ======================================================
//      SEND ALL LIVE DATA TO THE WEBSITE
// ======================================================

void handleData() {

  String json = "{";

  json += "\"gyroX\":" + String(latestGyroX, 3) + ",";
  json += "\"gyroY\":" + String(latestGyroY, 3) + ",";
  json += "\"gyroZ\":" + String(latestGyroZ, 3) + ",";
  json += "\"angularVelocity\":" + String(latestAngularVelocity, 3) + ",";
  json += "\"raw\":" + String(latestRawForce, 0) + ",";
  json += "\"slidingRaw\":" + String(latestSlidingRaw, 0) + ",";
  json += "\"slidingPower\":" + String(latestSlidingPower, 2);

  json += "}";

  server.send(200, "application/json", json);
}

// ======================================================
//                        SETUP
// ======================================================

void setup() {

  int ret;

  Serial.begin(115200);

  // ---------- IMU setup ----------

  fspi = new SPIClass(FSPI);

  fspi->begin(CLK_pin, MISO_pin, MOSI_pin, CS_pin);

  pinMode(CS_pin, OUTPUT);

  digitalWrite(CS_pin, HIGH);

  IMU = new ICM42670(*fspi, CS_pin);

  // Manual WHO_AM_I check
  digitalWrite(CS_pin, LOW);

  fspi->transfer(0x75 | 0x80);

  uint8_t who_am_i = fspi->transfer(0x00);

  digitalWrite(CS_pin, HIGH);

  Serial.print("Manual WHO_AM_I check: 0x");
  Serial.println(who_am_i, HEX);

  if (who_am_i != 0x67) {

    Serial.println("WARNING: Chip ID mismatch!");

  } else {

    Serial.println("IMU detected correctly.");
  }

  ret = IMU->begin();

  Serial.print("IMU begin returned: ");
  Serial.println(ret);

  if (ret != 0) {

    Serial.println("IMU initialization failed");

    while (1)
      ;
  }

  IMU->startAccel(100, 16);
  IMU->startGyro(100, 2000);

  // ---------- HX711 setup ----------

  pinMode(hxClockPin, OUTPUT);
  pinMode(hxDataPin, INPUT);

  delay(100);

  // ======================================================
  //                    INITIAL CALIBRATION
  // ======================================================


  for (int i = 0; i < samples; i++) {

    initialForce += readHX711();
  }

  initialForce /= samples;

  // ======================================================
  //                    WIFI SETUP
  // ======================================================

  WiFi.softAP(ssid, password);

  Serial.println("Access Point Started");

  IPAddress IP = WiFi.softAPIP();

  Serial.print("ESP32 IP Address: ");
  Serial.println(IP);

  // ======================================================
  //                    WEBSITE ENDPOINTS
  // ======================================================

  server.on("/", handleRoot);

  server.on("/data", handleData);

  server.begin();

  Serial.println("Web server started");

  // Start the first measurement period
  measurementStartTime = millis();

  Serial.print("Initial HX711 average: ");
  Serial.println(initialForce);
}

// ======================================================
//                        LOOP
// ======================================================

void loop() {

  // ======================================================
  //                    READ IMU
  // ======================================================

  inv_imu_sensor_event_t imu_event;

  IMU->getDataFromRegisters(imu_event);

  float gyroX = imu_event.gyro[0] / 16.4 * 0.0174533;
  float gyroY = imu_event.gyro[1] / 16.4 * 0.0174533;
  float gyroZ = imu_event.gyro[2] / 16.4 * 0.0174533;

  float angularVelocity = sqrt(gyroX * gyroX + gyroY * gyroY + gyroZ * gyroZ);

  gyroSumX += gyroX;
  gyroSumY += gyroY;
  gyroSumZ += gyroZ;
  angVelSum += angularVelocity;
  imuSampleCount++;

  // ======================================================
  //                    READ HX711
  // ======================================================

  long measuredForce = readHX711();

  hx711Sum += abs(measuredForce - initialForce);
  hx711Count++;

  // Update every second
  if (millis() - measurementStartTime >= measurementInterval) {

    // 1. Calculate 1-second averages
    float avgGyroX = gyroSumX / imuSampleCount;
    float avgGyroY = gyroSumY / imuSampleCount;
    float avgGyroZ = gyroSumZ / imuSampleCount;
    float avgAngularVelocity = angVelSum / imuSampleCount;
    float averageHX711 = hx711Sum / hx711Count;

    // 2. Update 3-Second Sliding Window for Raw Force
    rawWindow[rawWindowIndex] = averageHX711;
    rawWindowIndex = (rawWindowIndex + 1) % windowSize;

    float rawSlidingSum = 0;
    for (int i = 0; i < windowSize; i++) {
      rawSlidingSum += rawWindow[i];
    }
    float slidingRaw = rawSlidingSum / windowSize;
    float torque = 0.000108 * slidingRaw - 0.744;

    // 3. Calculate 1-Second Power & Update 3-Second Sliding Power Window
    float oneSecondPower = torque * avgAngularVelocity;

    powerWindow[windowIndex] = oneSecondPower;
    windowIndex = (windowIndex + 1) % windowSize;

    float powerSlidingSum = 0;
    for (int i = 0; i < windowSize; i++) {
      powerSlidingSum += powerWindow[i];
    }
    float slidingPower = powerSlidingSum / windowSize;
    slidingPower -= 40;

    // 5. Save globals
    latestGyroX = avgGyroX;
    latestGyroY = avgGyroY;
    latestGyroZ = avgGyroZ;
    latestAngularVelocity = avgAngularVelocity;
    latestRawForce = averageHX711;
    latestSlidingRaw = slidingRaw;
    latestSlidingPower = slidingPower;

    Serial.print("lastestSlidingPower");
    Serial.println(latestSlidingPower);

    // 6. Reset ALL accumulators
    hx711Sum = 0;
    hx711Count = 0;
    gyroSumX = 0;
    gyroSumY = 0;
    gyroSumZ = 0;
    angVelSum = 0;
    imuSampleCount = 0;

    measurementStartTime = millis();
  }

  // ======================================================
  //                    HANDLE WEBSITE
  // ======================================================

  server.handleClient();
}

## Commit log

2024-08-04 moving stuff to new repo + board layout redesign
    [BAT-HLD-001-THM.stp, TYPE-C-31-M-12.step, aug1save.kicad_pcb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]
2024-08-04 swapped imu, minor changes, renaming
    [BAT-HLD-001-THM.stp, TYPE-C-31-M-12.step, aug1save.kicad_pcb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]
2024-08-04 redid some traces
    [power.kicad_pcb, power.kicad_sch]
2024-08-06 added back silkscreen
    [power.kicad_pcb]
2024-10-31 major changes
    [aug1save.kicad_pcb, no_diode.kicad_pcb, power.kicad_pcb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]
2024-11-17 Final Check and did the production files
    [power.kicad_pcb]
2025-07-14 Rev 2 Initial Files
    [BAT-HLD-001-THM.stp, TYPE-C-31-M-12.step, power_rev2.kicad_pcb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]
2026-02-03 create nexus_power_rev3
    [HX711.step, final hpv power.kicad_pcb, final hpv power.kicad_sch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]
2026-02-04 Organized rev3 and rev4
    Organized rev3 and rev4
    [HX711.step, final hpv power.kicad_pcb, final hpv power.kicad_sch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]
2026-02-07 Update for resolder
    added pull up resistors and changed j2 footprint
    [nexus_power_rev3.kicad_pcb, nexus_power_rev3.kicad_sch]
2026-02-20 fixed up things for justin to look
    fixed up things for justin to look
    [final hpv power.kicad_pcb, final hpv power.kicad_sch]
2026-02-25 Update final hpv power.kicad_pcb
    [final hpv power.kicad_pcb]
2026-02-25 Fixed schematic based on Noah's notes from Justin
    [final hpv power.kicad_sch]
2026-02-27 Updated PCB and schematic for esp32 s3 wroom
    [final hpv power.kicad_pcb, final hpv power.kicad_sch]
2026-02-27 Rewired the HX711 on pcb and shrunk pcb size
    [final hpv power.kicad_pcb]
2026-02-28 Fixing up PCB
    added pull up resistor, replaced esp footprint, added header
    made are a lot smaller
    [final hpv power.kicad_pcb, final hpv power.kicad_sch]
2026-03-01 created BOM
    updated symbol fields
    [final hpv power.kicad_sch]
2026-03-02 connected TX and RX pins on MCU to header
    [final hpv power.kicad_pcb, final hpv power.kicad_sch]
2026-03-02 last fixes
    moved usb cconnector to edge, added more silkscreen, added tx and rx to breakout header
    [final hpv power.kicad_pcb]
2026-03-04 Final fixes
    [final hpv power.kicad_pcb, final hpv power.kicad_sch]
2026-03-05 Added board maker name
    [final hpv power.kicad_pcb]
2026-04-11 rev5 files
    [rev5.kicad_pcb, rev5.kicad_sch]
2026-04-11 UPDATE HEADER
    [rev5.kicad_sch]
2026-04-19 Rev 5 changes
    [rev5.kicad_pcb, rev5.kicad_sch]
2026-04-20 wired the pcb
    [rev5.kicad_pcb]
2026-04-20 small changes to the traces
    [rev5.kicad_pcb]
2026-04-20 fixed header traces
    [rev5.kicad_pcb]
2026-04-21 Final touchups and cleaned up layout
    [rev5-B_Cu.gbr, rev5-B_Mask.gbr, rev5-B_Paste.gbr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]
2026-09-10 added power meter code
2026-09-10 Optimized the firmware so power and angular velocity values update at a faster rate on the web server.
2026-09-29 Updated power code to achieve 80% power meter accuracy
